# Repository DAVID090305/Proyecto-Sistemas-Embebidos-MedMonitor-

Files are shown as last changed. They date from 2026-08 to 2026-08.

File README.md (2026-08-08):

# Proyecto-Sistemas-Embebidos-MedMonitor-
# MedMonitor: Sistema de Telemetría Médica IoT 🩺

Monitor biométrico portátil basado en ESP32 para la medición de temperatura corporal, frecuencia cardíaca y saturación de oxígeno (SpO2) en tiempo real. 

## 📌 Características Principales
* **Adquisición No Invasiva:** Sensores MAX30102 (SpO2/BPM) y MLX90614 (Temperatura).
* **Edge Computing:** Servidor web local alojado en el propio ESP32 (modo Access Point).
* **Alertas Clínicas:** Clasificación de estado mediante un semáforo LED y notificaciones guiadas por voz (Módulo I2S MAX98357A).
* **Autonomía:** Operación continua >4 horas mediante batería LiPo y elevador Boost.

## 📂 Estructura del Repositorio
* `/Firmware`: Código fuente en C++ (PlatformIO / VS Code).
* `/Hardware`: Diagramas de conexión (Fritzing) y diseño de circuito impreso PCB (Proteus).
* `/Mechanics`: Modelos 3D de la carcasa (Archivo STL).

## 🛠️ Tecnologías y Herramientas
* **Microcontrolador:** ESP32 DevKit V1
* **Entorno de Desarrollo:** Visual Studio Code + PlatformIO
* **Diseño Electrónico:** Proteus ARES/ISIS & Fritzing

---
*Proyecto desarrollado para la materia de Sistemas Embebidos - ESPOL.*

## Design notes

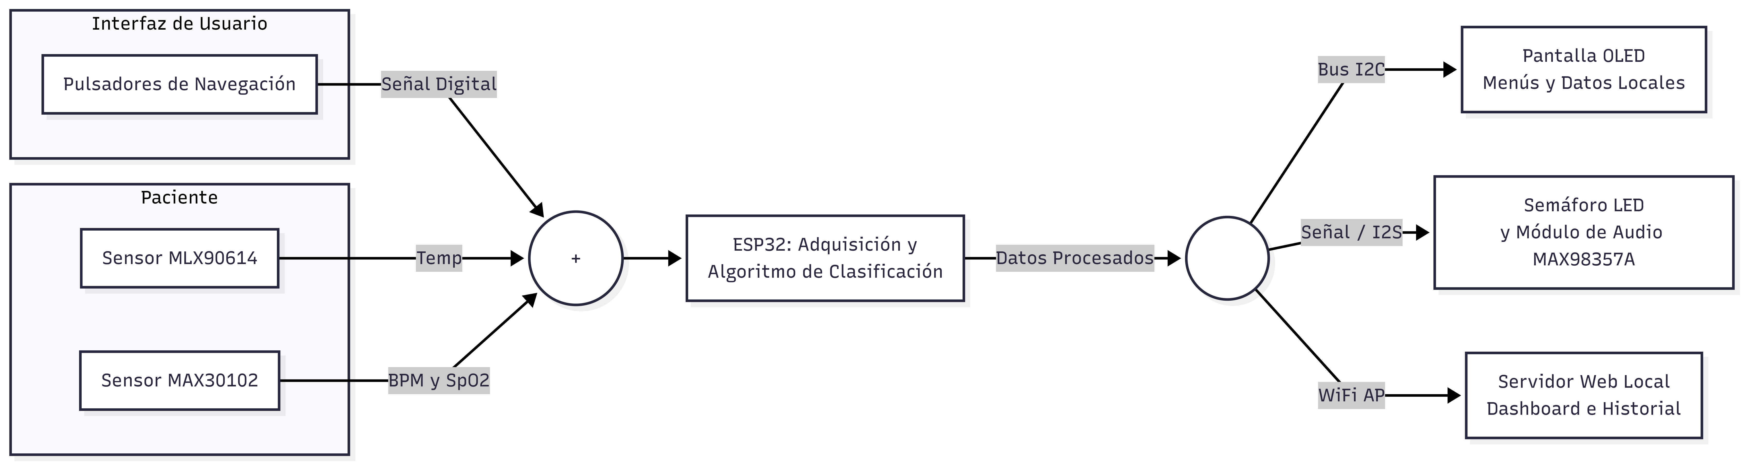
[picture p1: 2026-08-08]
Hardware/Diagrama de flujo del proyecto/Sensor Data Acquisition-2026-08-08-230845.png

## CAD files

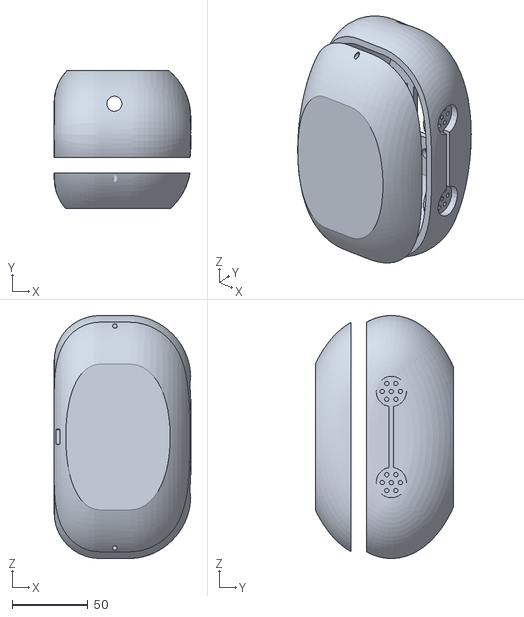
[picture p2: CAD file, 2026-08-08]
Mechanics/Baymax (1).stl
90.0 x 91.2 x 160.0

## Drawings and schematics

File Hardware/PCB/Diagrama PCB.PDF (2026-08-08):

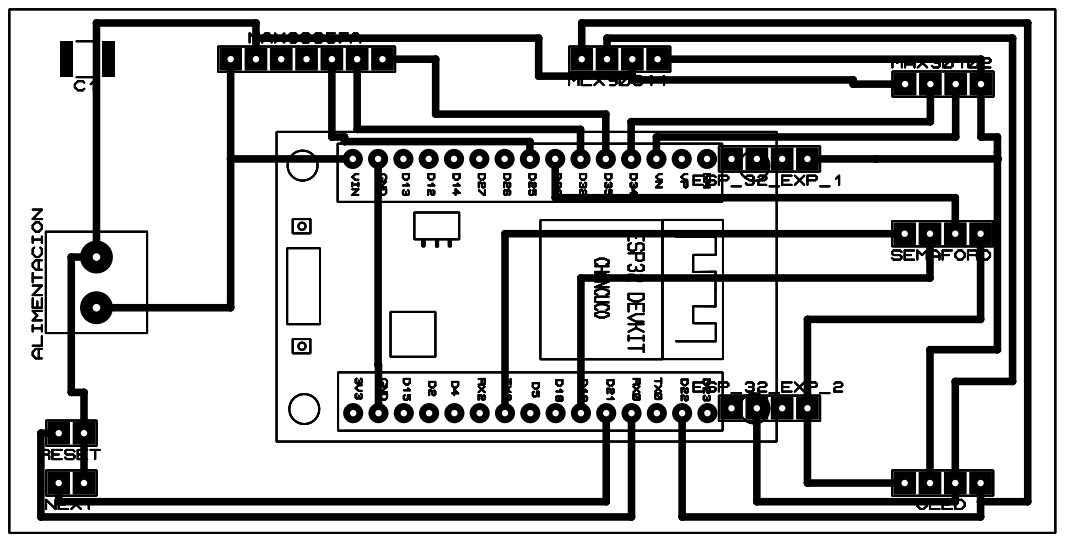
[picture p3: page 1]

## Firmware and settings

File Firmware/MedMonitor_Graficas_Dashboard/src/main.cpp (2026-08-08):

#include <Arduino.h>
#include <Wire.h>
#include <EEPROM.h>
#include <WiFi.h>
#include <WebServer.h>
#include <Adafruit_GFX.h>
#include <Adafruit_SH110X.h>
#include <Adafruit_MLX90614.h>
#include "MAX30105.h"
#include "heartRate.h"
#include "spo2_algorithm.h"
#include <LittleFS.h>
#include "Audio.h"

#define SCREEN_WIDTH 128
#define SCREEN_HEIGHT 64

// LED_VERDE y LED_AMARILLO estan en GPIO4/5 (se movieron de GPIO25/26 para
// liberar esos pines, que ahora usamos para I2S / audio).
#define LED_VERDE 4
#define LED_AMARILLO 5
#define LED_ROJO 27

#define BTN_SIGUIENTE 18
#define BTN_REINICIAR 19

// --- Audio (MAX98357A por I2S) ---
#define I2S_BCLK 26
#define I2S_LRC 25
#define I2S_DOUT 14

// Potenciometro de volumen (cursor a este pin, extremos a 3.3V y GND)
#define VOLUME_POT_PIN 34

#define EEPROM_SIZE 200
#define SSID1_ADDR 0
#define PASS1_ADDR 50
#define SSID2_ADDR 100
#define PASS2_ADDR 150

#define MAX_REGISTROS 10

Adafruit_SH1106G display(SCREEN_WIDTH, SCREEN_HEIGHT, &Wire, -1);
Adafruit_MLX90614 mlx = Adafruit_MLX90614();
MAX30105 particleSensor;

// Bus I2C #2, exclusivo para el MAX30102
TwoWire I2C_PULSO = TwoWire(1);
#define SDA2_PIN 32
#define SCL2_PIN 33

WebServer server(80);
Audio audio;

const char* ap_ssid = "MedMonitor_AP";
const char* ap_password = "12345678";

const byte RATE_SIZE = 10;
byte rates[RATE_SIZE];
byte rateSpot = 0;
byte bpmContador = 0;

long lastBeat = 0;
float bpm = 0;
int bpmProm = 0;
long irValue = 0;

float temp = 0;
float tempAmb = 0;

// --- Oximetro de pulso (SpO2) ---
#define SPO2_BUFFER_SIZE 100
uint32_t irBuffer[SPO2_BUFFER_SIZE];
uint32_t redBuffer[SPO2_BUFFER_SIZE];
int spo2BufferIndex = 0;

int32_t spo2Calculado = 0;
int8_t spo2Valido = 0;
int32_t hrCalculado = 0;
int8_t hrValidoAlgoritmo = 0;

int spo2Actual = 0;

unsigned long lastDisplayUpdate = 0;
const unsigned long DISPLAY_INTERVAL = 500;

bool heartBig = false;

// --- Carrusel de slides del OLED (BPM / SpO2 / Temp), controlado por botones ---
int slideActual = 0;
const int TOTAL_SLIDES = 3;

// Antirrebote (debounce) para los 2 pulsadores
const unsigned long DEBOUNCE_DELAY = 50; // ms

bool estadoSiguiente = HIGH;
bool ultimaLecturaSiguiente = HIGH;
unsigned long ultimoDebounceSiguiente = 0;

bool estadoReiniciar = HIGH;
bool ultimaLecturaReiniciar = HIGH;
unsigned long ultimoDebounceReiniciar = 0;

// Captura automatica unificada
bool dedoPuesto = false;
unsigned long dedoPuestoDesde = 0; // millis() de cuando empezo el contacto actual
int ultimoBpmValido = 0;
int bpmFinalAuto = 0;
bool bpmCapturado = false;

int ultimoSpo2Valido = 0;
int spo2FinalAuto = 0;
bool spo2Capturado = false;

float tempSumAuto = 0;
int tempCountAuto = 0;
float tempFinalAuto = 0;
bool tempCapturada = false;
bool tempPresente = false; // "objeto en rango valido" equivalente al dedoPuesto
unsigned long tempPresenteDesde = 0; // millis() de cuando empezo el contacto actual

// --- Maquina de estados del flujo guiado: BPM+SpO2 -> Temperatura -> Final ---
enum EtapaMedicion { ETAPA_BPM_SPO2, ETAPA_TEMP, ETAPA_FINAL };
EtapaMedicion etapaActual = ETAPA_BPM_SPO2;

struct Registro {
  String nombre;
  int edad;
  int bpm;
  int spo2;
  float temp;
  String estado;   // gravedad combinada (Normal/Advertencia/Alerta) -> color
  String chequeo;  // resumen clinico legible para mostrar en el historial
};

Registro historial[MAX_REGISTROS];
int totalRegistros = 0;

// --- Cola de audio ---
// Permite encolar varias frases para que se reproduzcan una despues de la
// otra sin cortarse (la libreria interrumpe el audio actual si le pedis
// reproducir uno nuevo antes de que termine, por eso encolamos en vez de
// llamar a audio.connecttoFS() directo cuando puede haber mas de una frase
// seguida).
#define AUDIO_QUEUE_SIZE 4
String colaAudio[AUDIO_QUEUE_SIZE];
int colaAudioLen = 0;

void encolarAudio(const char* ruta) {
  if (colaAudioLen < AUDIO_QUEUE_SIZE) {
    colaAudio[colaAudioLen] = String(ruta);
    colaAudioLen++;
  }
}

void limpiarColaAudio() {
  colaAudioLen = 0;
}

void procesarColaAudio() {
  if (!audio.isRunning() && colaAudioLen > 0) {
    String siguiente = colaAudio[0];
    for (int i = 1; i < colaAudioLen; i++) colaAudio[i - 1] = colaAudio[i];
    colaAudioLen--;
    audio.connecttoFS(LittleFS, siguiente.c_str());
  }
}

// --- Volumen por potenciometro (GPIO34) ---
int volumenActual = -1; // -1 fuerza que se aplique la primera lectura
unsigned long ultimaLecturaVolumen = 0;
const unsigned long INTERVALO_LECTURA_VOLUMEN = 200; // ms

void actualizarVolumen() {
  if (millis() - ultimaLecturaVolumen < INTERVALO_LECTURA_VOLUMEN) return;
  ultimaLecturaVolumen = millis();

  int lectura = analogRead(VOLUME_POT_PIN); // 0-4095
  int nuevoVolumen = map(lectura, 0, 4095, 0, 21);
  nuevoVolumen = constrain(nuevoVolumen, 0, 21);

  if (nuevoVolumen != volumenActual) {
    volumenActual = nuevoVolumen;
    audio.setVolume(volumenActual);
  }
}

void escribirStringEEPROM(int direccion, String texto) {
  for (int i = 0; i < texto.length(); i++) EEPROM.write(direccion + i, texto[i]);
  EEPROM.write(direccion + texto.length(), '\0');
  EEPROM.commit();
}

String leerStringEEPROM(int direccion) {
  String texto = "";
  char c;
  while ((c = EEPROM.read(direccion++)) != '\0') texto += c;
  return texto;
}

void apagarSemaforo() {
  digitalWrite(LED_VERDE, LOW);
  digitalWrite(LED_AMARILLO, LOW);
  digitalWrite(LED_ROJO, LOW);
}

String obtenerEstadoBPM(int bpm) {
  if (bpm == 0) return "Midiendo";
  if (bpm >= 60 && bpm <= 100) return "Normal";
  if ((bpm >= 40 && bpm < 60) || (bpm > 100 && bpm <= 120)) return "Advertencia";
  return "Alerta";
}

String obtenerEstadoSpO2(int spo2) {
  if (spo2 == 0) return "Midiendo";
  if (spo2 >= 95) return "Normal";
  if (spo2 >= 90) return "Advertencia";
  return "Alerta";
}

String obtenerEstadoTemp(float t) {
  if (t == 0.0) return "Midiendo";
  if (t >= 36.0 && t <= 37.5) return "Normal";
  if ((t >= 35.0 && t < 36.0) || (t > 37.5 && t <= 38.5)) return "Advertencia";
  return "Alerta";
}

// --- Etiquetas clinicas especificas por parametro (solo para mostrar en pantalla) ---
// Nota: la gravedad interna para el semaforo sigue usando obtenerEstadoBPM/SpO2/Temp
// (Normal/Advertencia/Alerta) sin cambios; esto es unicamente el texto visible.

String etiquetaBPM(int bpm) {
  if (bpm == 0) return "Sin datos";
  if (bpm < 40) return "Bradicardia severa";
  if (bpm < 60) return "Bradicardia";
  if (bpm <= 100) return "Ritmo estable";
  if (bpm <= 120) return "Taquicardia";
  return "Taquicardia severa";
}

String etiquetaSpO2(int spo2) {
  if (spo2 == 0) return "Sin datos";
  if (spo2 < 90) return "Hipoxia";
  if (spo2 < 95) return "Hipoxia leve";
  return "Saturacion optima";
}

String etiquetaTemp(float t) {
  if (t == 0.0) return "Sin datos";
  if (t < 35.0) return "Hipotermia";
  if (t < 36.0) return "Hipotermia leve";
  if (t <= 37.5) return "Temperatura estable";
  if (t <= 38.5) return "Febricula";
  return "Fiebre";
}

// Convierte un estado individual en puntos de gravedad para el sistema de puntaje:
// Normal = 0, Advertencia = 1, Alerta = 2
int puntosDeEstado(String estado) {
  if (estado == "Alerta") return 2;
  if (estado == "Advertencia") return 1;
  return 0; // Normal
}

// Veredicto final por sistema de puntos (similar a un Early Warning Score clinico):
// cada signo aporta puntos segun su gravedad, se suman, y el semaforo depende
// del puntaje total. Asi, una sola anomalia leve no dispara alerta roja completa,
// pero varias anomalias juntas si escalan el estado.
//
// Excepcion de seguridad: una SpO2 critica (<90%) siempre fuerza Alerta de
// inmediato, sin importar el resto, porque una hipoxia real es peligrosa por
// si sola y no debe "diluirse" en el puntaje.
String obtenerEstado(int bpm, int spo2, float t) {
  String estadoBpm = obtenerEstadoBPM(bpm);
  String estadoSpo2 = obtenerEstadoSpO2(spo2);
  String estadoTemp = obtenerEstadoTemp(t);

  if (estadoBpm == "Midiendo" || estadoSpo2 == "Midiendo" || estadoTemp == "Midiendo") {
    return "Midiendo";
  }

  if (estadoSpo2 == "Alerta") return "Alerta";

  int puntos = puntosDeEstado(estadoBpm) + puntosDeEstado(estadoSpo2) + puntosDeEstado(estadoTemp);

  if (puntos == 0) return "Normal";
  if (puntos <= 2) return "Advertencia";
  return "Alerta";
}

// Arma un resumen clinico legible para el historial del dashboard.
String obtenerResumenClinico(int bpm, int spo2, float t) {
  String estadoBpm = obtenerEstadoBPM(bpm);
  String estadoSpo2 = obtenerEstadoSpO2(spo2);
  String estadoTemp = obtenerEstadoTemp(t);

  if (estadoBpm == "Midiendo" || estadoSpo2 == "Midiendo" || estadoTemp == "Midiendo") {
    return "Medicion incompleta";
  }

  String resumen = "";
  if (estadoBpm != "Normal") resumen += etiquetaBPM(bpm);
  if (estadoSpo2 != "Normal") {
    if (resumen != "") resumen += "; ";
    resumen += etiquetaSpO2(spo2);
  }
  if (estadoTemp != "Normal") {
    if (resumen != "") resumen += "; ";
    resumen += etiquetaTemp(t);
  }

  if (resumen == "") return "Paciente estable";
  return resumen;
}

void actualizarSemaforo(String estado) {
  apagarSemaforo();
  if (estado == "Normal") digitalWrite(LED_VERDE, HIGH);
  else if (estado == "Advertencia") digitalWrite(LED_AMARILLO, HIGH);
  else if (estado == "Alerta") digitalWrite(LED_ROJO, HIGH);
}

void guardarRegistro(String nombre, int edad) {
  if (nombre == "") nombre = "Paciente";

  Registro nuevo;
  nuevo.nombre = nombre;
  nuevo.edad = edad;
  nuevo.bpm = bpmCapturado ? bpmFinalAuto : bpmProm;
  nuevo.spo2 = spo2Capturado ? spo2FinalAuto : spo2Actual;
  nuevo.temp = tempCapturada ? tempFinalAuto : temp;

  nuevo.estado = obtenerEstado(nuevo.bpm, nuevo.spo2, nuevo.temp);
  nuevo.chequeo = obtenerResumenClinico(nuevo.bpm, nuevo.spo2, nuevo.temp);

  if (totalRegistros < MAX_REGISTROS) {
    historial[totalRegistros] = nuevo;
    totalRegistros++;
  } else {
    for (int i = 0; i < MAX_REGISTROS - 1; i++) historial[i] = historial[i + 1];
    historial[MAX_REGISTROS - 1] = nuevo;
  }

  tempCapturada = false;
  bpmCapturado = false;
  spo2Capturado = false;
  tempFinalAuto = 0;
  bpmFinalAuto = 0;
  spo2FinalAuto = 0;

  etapaActual = ETAPA_BPM_SPO2;
  slideActual = 0;
  dedoPuesto = false;
  ultimoBpmValido = 0;
  ultimoSpo2Valido = 0;
  tempPresente = false;
  tempSumAuto = 0;
  tempCountAuto = 0;

  apagarSemaforo();

  // Nota: la despedida (audio9) ya se reprodujo automaticamente al terminar
  // de medir (justo despues del resultado). Guardar en el dashboard es una
  // accion silenciosa que no debe interrumpir el audio que este sonando.
}

void dibujarCorazon(int x, int y, bool grande) {
  if (grande) {
    display.fillCircle(x + 8, y + 8, 7, SH110X_WHITE);
    display.fillCircle(x + 22, y + 8, 7, SH110X_WHITE);
    display.fillTriangle(x + 1, y + 11, x + 29, y + 11, x + 15, y + 30, SH110X_WHITE);
  } else {
    display.drawCircle(x + 8, y + 8, 6, SH110X_WHITE);
    display.drawCircle(x + 20, y + 8, 6, SH110X_WHITE);
    display.drawTriangle(x + 2, y + 11, x + 26, y + 11, x + 14, y + 27, SH110X_WHITE);
  }
}

// Devuelve 0 a 3 puntos suspensivos que van creciendo con el tiempo.
String puntosAnimados() {
  int n = (millis() / 400) % 4;
  String p = "";
  for (int i = 0; i < n; i++) p += ".";
  return p;
}

// Dibuja un punto que crece y encoge en bucle (indicador de "grabando").
void dibujarPulso(int x, int y) {
  int fase = (millis() / 150) % 6;
  int radio = (fase < 3) ? (fase + 1) : (6 - fase);
  display.fillCircle(x, y, radio, SH110X_WHITE);
}

void mostrarSlideBPM() {
  display.setTextSize(1);
  display.setCursor(0, 0);
  display.print("FRECUENCIA CARDIACA");

  dibujarCorazon(2, 16, heartBig);

  display.setTextSize(4);
  display.setCursor(46, 14);
  display.print(bpmFinalAuto);

  display.setTextSize(1);
  display.setCursor(0, 54);
  display.print(etiquetaBPM(bpmFinalAuto));
}

void mostrarSlideSpO2() {
  display.setTextSize(1);
  display.setCursor(0, 0);
  display.print("OXIGENACION (SpO2)");

  display.setTextSize(4);
  display.setCursor(20, 18);
  display.print(spo2FinalAuto);
  display.setTextSize(2);
  display.print("%");

  display.setTextSize(1);
  display.setCursor(0, 54);
  display.print(etiquetaSpO2(spo2FinalAuto));
}

void mostrarSlideTemp() {
  display.setTextSize(1);
  display.setCursor(0, 0);
  display.print("TEMPERATURA CORPORAL");

  display.setTextSize(4);
  display.setCursor(6, 18);
  display.print(tempFinalAuto, 1);

  display.setTextSize(2);
  display.print("C");

  display.setTextSize(1);
  display.setCursor(0, 54);
  display.print(etiquetaTemp(tempFinalAuto));
}

void mostrarEtapaBPMSpO2() {
  dibujarCorazon(2, 18, heartBig);

  display.setTextSize(1);
  display.setCursor(40, 14);
  display.print("BPM");
  display.setTextSize(2);
  display.setCursor(40, 26);
  if (bpmProm > 0) display.print(bpmProm);
  else display.print("--");

  display.setTextSize(1);
  display.setCursor(88, 14);
  display.print("SpO2");
  display.setTextSize(2);
  display.setCursor(88, 26);
  if (spo2Actual > 0) display.print(spo2Actual);
  else display.print("--");

  display.setTextSize(1);
  display.setCursor(0, 56);
  if (bpmCapturado || spo2Capturado) {
    display.print("Datos guardados");
    display.fillCircle(122, 5, 3, SH110X_WHITE);
  } else {
    display.print("Midiendo");
    display.print(puntosAnimados());
    dibujarPulso(122, 5);
  }
}

void mostrarEtapaTemp() {
  display.setTextSize(4);
  display.setCursor(10, 22);
  display.print(temp, 1);
  display.setTextSize(2);
  display.print("C");

  display.setTextSize(1);
  display.setCursor(0, 56);
  if (tempCapturada) {
    display.print("Datos guardados");
    display.fillCircle(122, 5, 3, SH110X_WHITE);
  } else {
    display.print("Midiendo");
    display.print(puntosAnimados());
    dibujarPulso(122, 5);
  }
}

void actualizarOLED(); // forward declaration, definida mas abajo

void actualizarSemaforoParaSlideActual() {
  switch (slideActual) {
    case 0: actualizarSemaforo(obtenerEstadoBPM(bpmFinalAuto)); break;
    case 1: actualizarSemaforo(obtenerEstadoSpO2(spo2FinalAuto)); break;
    case 2: actualizarSemaforo(obtenerEstadoTemp(tempFinalAuto)); break;
  }
}

void avanzarEtapa() {
  if (etapaActual == ETAPA_BPM_SPO2) {
    bool yaEstabaCapturado = bpmCapturado || spo2Capturado;

    // Resguardo: si el dedo sigue puesto y aun no se guardo, lo guardamos igual
    if (!bpmCapturado && bpmProm > 0) { bpmFinalAuto = bpmProm; bpmCapturado = true; }
    if (!spo2Capturado && spo2Actual > 0) { spo2FinalAuto = spo2Actual; spo2Capturado = true; }

    // Si por algun motivo no sonaron todavia (ej: presiono el boton sin
    // retirar el dedo primero), las encolamos aca como resguardo.
    if (!yaEstabaCapturado && (bpmCapturado || spo2Capturado)) {
      encolarAudio("/a3_indic2.mp3");
      encolarAudio("/a4_medirtemp.mp3");
    }

    etapaActual = ETAPA_TEMP;
    tempSumAuto = 0;
    tempCountAuto = 0;
    tempPresente = false;

  } else if (etapaActual == ETAPA_TEMP) {
    if (!tempCapturada) {
      tempFinalAuto = (tempCountAuto > 0) ? (tempSumAuto / tempCountAuto) : temp;
      tempCapturada = true;
      encolarAudio("/a5_tempok.mp3");
    }

    etapaActual = ETAPA_FINAL;
    slideActual = 2; // Temperatura fue el ultimo parametro medido
    actualizarSemaforoParaSlideActual();

    String estadoFinal = obtenerEstado(bpmFinalAuto, spo2FinalAuto, tempFinalAuto);
    if (estadoFinal == "Alerta") {
      encolarAudio("/a8_alerta.mp3");
    } else if (estadoFinal == "Advertencia") {
      encolarAudio("/a7_atencion.mp3");
    } else {
      encolarAudio("/a6_estable.mp3");
    }
    // Despedida encadenada justo despues de dictar el resultado
    encolarAudio("/a9_despedida.mp3");
  }
}

void reiniciarBufferSPO2(); // forward declaration, definida mas abajo

void reiniciarTodo() {
  etapaActual = ETAPA_BPM_SPO2;
  slideActual = 0;

  dedoPuesto = false;
  ultimoBpmValido = 0;
  ultimoSpo2Valido = 0;
  bpmCapturado = false;
  spo2Capturado = false;
  bpmFinalAuto = 0;
  spo2FinalAuto = 0;

  tempPresente = false;
  tempSumAuto = 0;
  tempCountAuto = 0;
  tempCapturada = false;
  tempFinalAuto = 0;

  bpm = 0;
  bpmProm = 0;
  rateSpot = 0;
  bpmContador = 0;
  for (byte i = 0; i < RATE_SIZE; i++) rates[i] = 0;
  reiniciarBufferSPO2();

  apagarSemaforo();

  limpiarColaAudio();
  encolarAudio("/a1_saludo.mp3");
  encolarAudio("/a2_indic1.mp3");
}

void manejarBotones() {
  bool refrescarYa = false;

  bool lecturaSiguiente = digitalRead(BTN_SIGUIENTE);
  if (lecturaSiguiente != ultimaLecturaSiguiente) {
    ultimoDebounceSiguiente = millis();
  }
  if ((millis() - ultimoDebounceSiguiente) > DEBOUNCE_DELAY) {
    if (lecturaSiguiente != estadoSiguiente) {
      estadoSiguiente = lecturaSiguiente;
      if (estadoSiguiente == LOW) {
        if (etapaActual == ETAPA_FINAL) {
          slideActual = (slideActual + 1) % TOTAL_SLIDES;
          actualizarSemaforoParaSlideActual();
        } else {
          avanzarEtapa();
        }
        refrescarYa = true;
      }
    }
  }
  ultimaLecturaSiguiente = lecturaSiguiente;

  bool lecturaReiniciar = digitalRead(BTN_REINICIAR);
  if (lecturaReiniciar != ultimaLecturaReiniciar) {
    ultimoDebounceReiniciar = millis();
  }
  if ((millis() - ultimoDebounceReiniciar) > DEBOUNCE_DELAY) {
    if (lecturaReiniciar != estadoReiniciar) {
      estadoReiniciar = lecturaReiniciar;
      if (estadoReiniciar == LOW) {
        reiniciarTodo();
        refrescarYa = true;
      }
    }
  }
  ultimaLecturaReiniciar = lecturaReiniciar;

  if (refrescarYa) {
    actualizarOLED();
  }
}

void actualizarOLED() {
  display.clearDisplay();
  display.setTextColor(SH110X_WHITE);

  switch (etapaActual) {
    case ETAPA_BPM_SPO2:
      mostrarEtapaBPMSpO2();
      break;

    case ETAPA_TEMP:
      mostrarEtapaTemp();
      break;

    case ETAPA_FINAL:
      switch (slideActual) {
        case 0: mostrarSlideBPM(); break;
        case 1: mostrarSlideSpO2(); break;
        case 2: mostrarSlideTemp(); break;
      }
      break;
  }

  display.display();
}
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
void loop() {
  server.handleClient();

  // Mantiene el audio sonando y dispara el siguiente de la cola cuando el
  // actual termina. Debe llamarse seguido, sin bloquear.
  audio.loop();
  procesarColaAudio();
  actualizarVolumen();

  // 1. Leer temperatura y aplicar compensacion
  float tempPiel = mlx.readObjectTempC();
  tempAmb = mlx.readAmbientTempC();
  bool objetoTempPresente = (tempPiel >= 27.0 && tempPiel <= 35.5);

  if (objetoTempPresente) {
    temp = tempPiel + (0.30 * (37.0 - tempAmb));
  } else {
    temp = tempPiel;
  }

  // 2. Extraer datos del sensor MAX30105
  particleSensor.check();
  while (particleSensor.available()) {
    irValue = particleSensor.getFIFOIR();
    uint32_t redValue = particleSensor.getFIFORed();
    particleSensor.nextSample();

    if (checkForBeat(irValue)) {
      heartBig = !heartBig;
      long now = millis();
      long delta = now - lastBeat;
      lastBeat = now;
      float bpmInstantaneo = 60.0 / (delta / 1000.0);

      if (bpmInstantaneo > 45 && bpmInstantaneo < 200) {
        bpm = bpmInstantaneo;
        rates[rateSpot++] = (byte)bpm;
        rateSpot %= RATE_SIZE;
        if (bpmContador < RATE_SIZE) bpmContador++;

        int suma = 0;
        for (byte i = 0; i < bpmContador; i++) suma += rates[i];
        bpmProm = suma / bpmContador;
      }
    }

    irBuffer[spo2BufferIndex] = irValue;
    redBuffer[spo2BufferIndex] = redValue;
    spo2BufferIndex++;

    if (spo2BufferIndex >= SPO2_BUFFER_SIZE) {
      maxim_heart_rate_and_oxygen_saturation(irBuffer, SPO2_BUFFER_SIZE, redBuffer,
                                             &spo2Calculado, &spo2Valido,
                                             &hrCalculado, &hrValidoAlgoritmo);
      if (spo2Valido && spo2Calculado > 0 && spo2Calculado <= 100) {
        spo2Actual = spo2Calculado;
      }

      for (int i = 25; i < SPO2_BUFFER_SIZE; i++) {
        irBuffer[i - 25] = irBuffer[i];
        redBuffer[i - 25] = redBuffer[i];
      }
      spo2BufferIndex = SPO2_BUFFER_SIZE - 25;
    }
  }

  // 3. Captura automatica: solo corre la logica de la etapa actual
  if (etapaActual == ETAPA_BPM_SPO2) {
    actualizarCapturaBPMSpO2();
  } else if (etapaActual == ETAPA_TEMP) {
    actualizarCapturaTemp(objetoTempPresente);
  }

  // 4. Si no hay dedo en el sensor de pulso, reiniciamos sus buffers
  if (irValue < 20000) {
    bpm = 0;
    bpmProm = 0;
    rateSpot = 0;
    bpmContador = 0;
    for (byte i = 0; i < RATE_SIZE; i++) rates[i] = 0;
    reiniciarBufferSPO2();
  }

  // 5. Botones
  manejarBotones();

  // Mientras se esta midiendo, refrescamos mas seguido para que la
  // animacion se vea fluida; en resultados alcanza con el intervalo normal.
  unsigned long intervaloActual = (etapaActual == ETAPA_FINAL) ? DISPLAY_INTERVAL : 150;

  if (millis() - lastDisplayUpdate >= intervaloActual) {
    lastDisplayUpdate = millis();
    actualizarOLED();
  }

  // Segunda llamada, para que el audio se sirva mas seguido y no se corte
  // por el trabajo del OLED/sensores/WiFi de esta vuelta del loop.
  audio.loop();

  delay(1);
}

// Callback requerido por la libreria de audio (opcional, solo para debug)
void audio_info(const char *info) {
  Serial.print("audio_info: ");
  Serial.println(info);
}
